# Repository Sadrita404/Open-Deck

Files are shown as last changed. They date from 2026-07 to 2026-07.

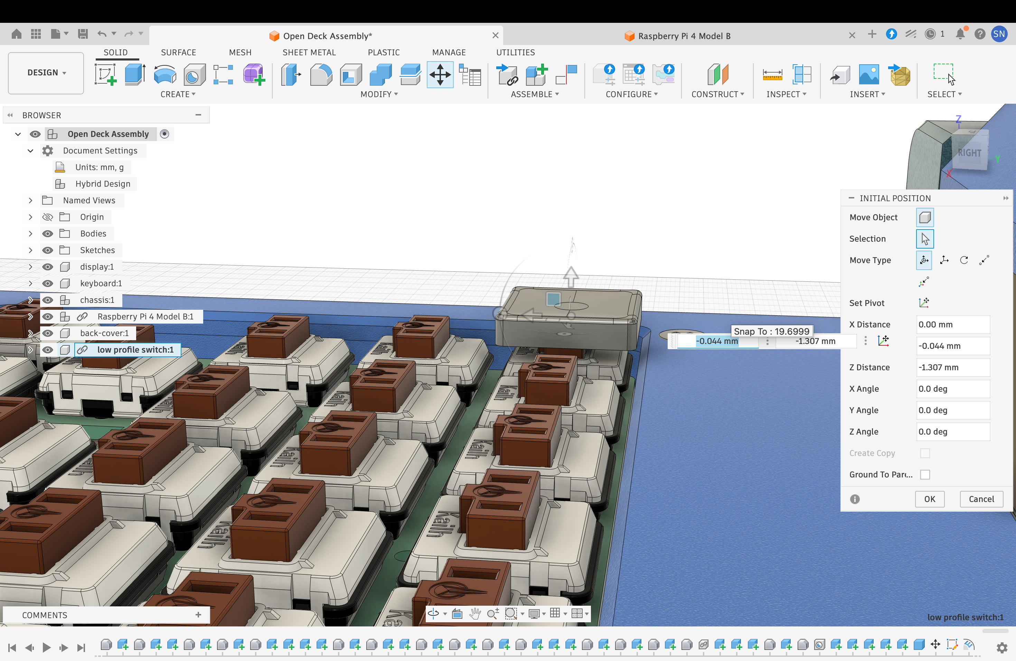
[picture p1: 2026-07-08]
Images/28.png

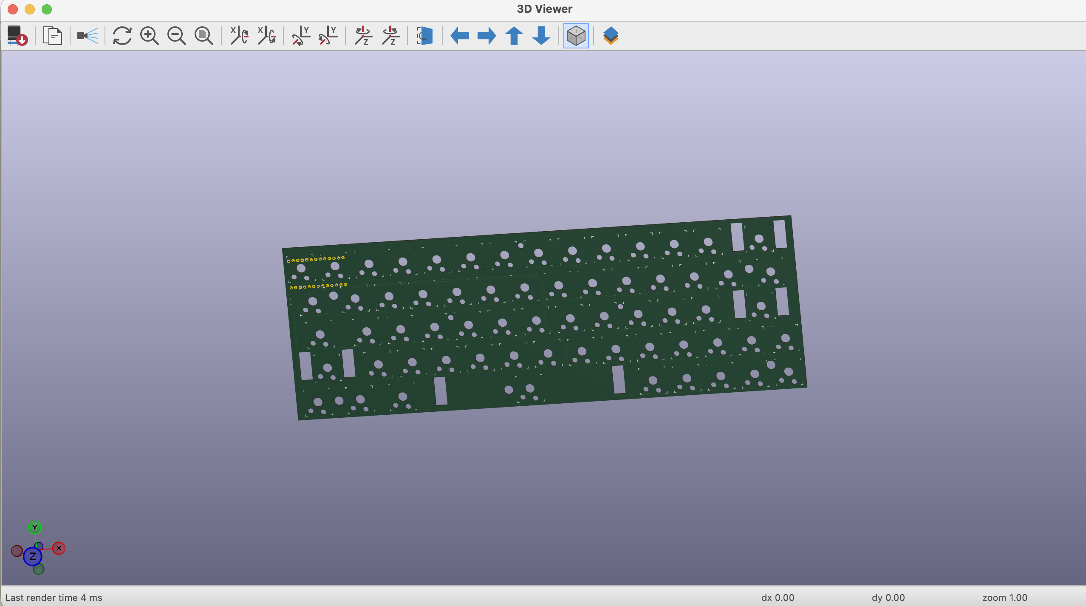
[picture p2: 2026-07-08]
Images/50.png

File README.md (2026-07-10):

<div align="center">
  <table border="0" cellpadding="0" cellspacing="0">
    <tr>
      <td align="center" style="background: #ffffff; border: 1px solid #d0d7de; border-radius: 12px; padding: 16px; box-shadow: 0 4px 12px rgba(0,0,0,0.05);">
        Rough Layout For The PCB
        <div style="margin-top: 12px; font-family: -apple-system, BlinkMacSystemFont, 'Segoe UI', Helvetica, Arial, sans-serif; font-size: 13px; color: #57606a; font-weight: 500;">
      </td>
    </tr>
  </table>
</div>

|Title | Open Deck |
|:-- |:--|
|Author | Sadrita Neogi|

## Overview
It is an fully Open Source Cyber Deck called **Open Deck** Which I have made from scratch it uses an Raspberry Pi 5 Model 2GB RAM as the main compute module and I have made an custom low profile keyboard for this project so that it will perfectly match with the Open Deck . And it also has an pico camera as the webcam .

## Why I chose this project?
Actually I am building an rocket launching system pad and for that I need to track gps , weather , Wind speed , direction a lot on the ground and for that I need something portable that I can use for it and which is seperate from my laptop so that it can run this task independently . Also I am huge fan of this hacking kind of hardware and an cyber deck is something like that so for that reason I have built it ..

##  How to use this project

This project can be used in multiple ways, depending upon the user need  like we can perform basic task like web browsing to fully automate our home to automate our 3-D printers also running some local AI agents into it. There are many possibilities through which we can use this project.For me I will use it to make some projects to be automated and also use in the rocket launching pad for those tasks .

## Features

* It uses custom low profile keyboard 
* It has web cam (pico cam )
* Runs on battery as well an power
* Uses Raspberry Pi 5 Model 2GB RAM
* Compact and Portable 
* Can run local models
* Custom 3d Printed Enclosure
* Fully Open Source 

Schematic

## Software 

For software I will use linux for this build and it is also open source 

**[https://www.raspberrypi.com/software/](https://www.raspberrypi.com/software/)**

### Linux 

**[https://github.com/raspberrypi/linux](https://github.com/raspberrypi/linux)**

### The Linux kernel Documentation - [DOC Link ](https://www.raspberrypi.com/documentation/computers/linux_kernel.html)

In the raspberrypi [website](https://www.raspberrypi.com/documentation/computers/linux_kernel.html) the documentation about downloading and use cases of Linux for raspberrypi is well documented and everything is written there, so please go check it out and read through the documentation. It is well documented and everything is listed there.

---

|  |  | Building Process |  |  |
| :-: | :-: | :-: | :-: | :-: |
| sketch |  |  |  |  |
|  |  |  |  |  |
|  |  |  |  |  |
|  |  |  |  |  |
|  |  |  |  |  |
|  |  |  |  |  |

## Fusion Renders 

<div align="center">

Render 1
Render 3
Render 4
Render 2
Render 6
Render 5

</div>

<div align="center">
  <h2> Bill of Materials</h2>
</div>

| Component Name | Purpose | Qty | Total Price | Source Link | Distributor |
| :--- | :--- | :---: | :---: | :---: | :---: |
| **Raspberry Pi 5 Model B - 2GB RAM** | The Main Board | 1 | $79.20 | [Quartz Components](https://quartzcomponents.com/products/raspberry-pi-5-model-b-2-gb-ram) | Quartzcomponents |
| **HD Portable Monitor IPS Panel Display** | The Main Display | 1 | $58.40 | [Amazon](https://www.amazon.in/Smartchoice-Portable-Adaptive-Sync-Ultra-Slim-Speakers/dp/B082MDD1QZ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) | Amazon |
| **LI-ION BATTERY (3400mAh)** | To power up the circuit | 6 | $23.70 | [Robu](https://robu.in/product/lg-18650-mj1-3400mah-3c-li-ion-battery/) | Robu |
| **Raspberry Pi Camera NOIR V2** | For Webcam | 1 | $16.60 | [Robu](https://robu.in/product/raspberry-pi-camera-noir-v2/) | Robu |
| **Keyboard PCB** | For the main Keyboard | 1 | $17.40 | [JLCPCB](https://jlcpcb.com/) | JLCPCB |
| **Low Profile Brown Switches** | For the Keyboard | 64 | $26.60 | [Stackskb](https://stackskb.com/store/ttc-low-profile-brown-switches-tactile/) | Stackskb |
| **Keycap Set** | For the Keyboard Switch | 1 | $12.00 | [Meckeys](https://meckeys.com/shop/accessories/keyboard-accessories/keycaps/black-cartoon-keycap-set/) | Meckeys |
| **Keyboard Stabilizer** | For the Keyboard | 1 | $10.60 | [Meckeys](https://meckeys.com/shop/accessories/keyboard-accessories/more/glorious-goat-stabilizers/) | Meckeys |
| **Stereo Enclosed Speaker - 3W** | For Sound | 1 | $5.20 | [Robu](https://robu.in/product/dfrobot-fit0502-stereo-enclosed-speaker-3w-8%cf%89/) | Robu |
| **Channel Digital Amplifier Board** | For the Speakers | 1 | $1.50 | [Robu](https://robu.in/product/tpa3110-mono-channel-digital-amplifier-board-30w-power-amplifier-module/) | Robu |
| **Screws Assorted set** | For fixing the frame | 1 | $2.60 | [OnlyScrews](https://onlyscrews.in/products/m3-allen-button-head-ss304-assorted-box) | OnlyScrew |
| **Li - Po BMS module** | For battery protection | 1 | $0.70 | [Robu](https://robu.in/product/3s-12v-18650-lithium-battery-protection-board-12v-10a-overcharge-overcurrent-protection/) | Robu |
| **NRF52840 Development Board** | For the keyboard Controller | 1 | $5.60 | [Electropi](https://www.electropi.in/promicro-nrf52840-development-board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) | Electropi |
| **1N4148 1W Zener Diode** | For the keyboard | 64 | $1.00 | [Robu](https://robu.in/product/1n4148-1w-zener-diode-pack-of-50/) | Robu |
| **20 pin header socket** | For the keyboard | 1 | $0.20 | [Robu](https://robu.in/product/2-54mm-1x20-pin-female-single-row-straight-header-strip-pack-of-5/) | Robu |
| **Self Locking Switch** | For the power switch | 1 | $0.40 | [Robu](https://robu.in/product/r16-503a-plastic-self-locking-latching-switch-2pinoff-on/) | Robu |
| **USB-C hub module** | For the Cyber Deck Ports | 1 | $2.60 | [Robu](https://robu.in/product/smartelex-usb-hub-with-4x-usb-2-0-ports/) | Robu |
| **Raspberry Pi 5 Active Cooler** | To cool the Pi | 1 | $5.10 | [Robu](https://robu.in/product/official-raspberry-pi-5-active-cooler/) | Robu |
| **Flat Ribbon HDMI + Short Type-C Extensions** | For Display Connection | 1 | $1.50 | [Robu](https://robu.in/product/micro-hdmi-male-to-hdmi-male-adapter/) | Robu |
| **3d Print** | For the Case and the body | 1 | $0.00 | [Print Legion](https://printlegion.hackclub.com/) | #printing-legion |
| **Tax** | - | - | $3.60 | - | - |
| **Shipping** | incl. PCB | - | $22.00 | - | - |
| **Total** | - | - | $290.00 | - | - |
| **Total Round Off** | For Dollar rate fluctuation | - | $300.00 | - | - |

## Copyright and License
Copyright (c) 2026 Sadrita Neogi. All rights reserved.

All files are licensed under the MIT license. For more information, see the [LICENSE](LICENSE).

Project Under Hack Club

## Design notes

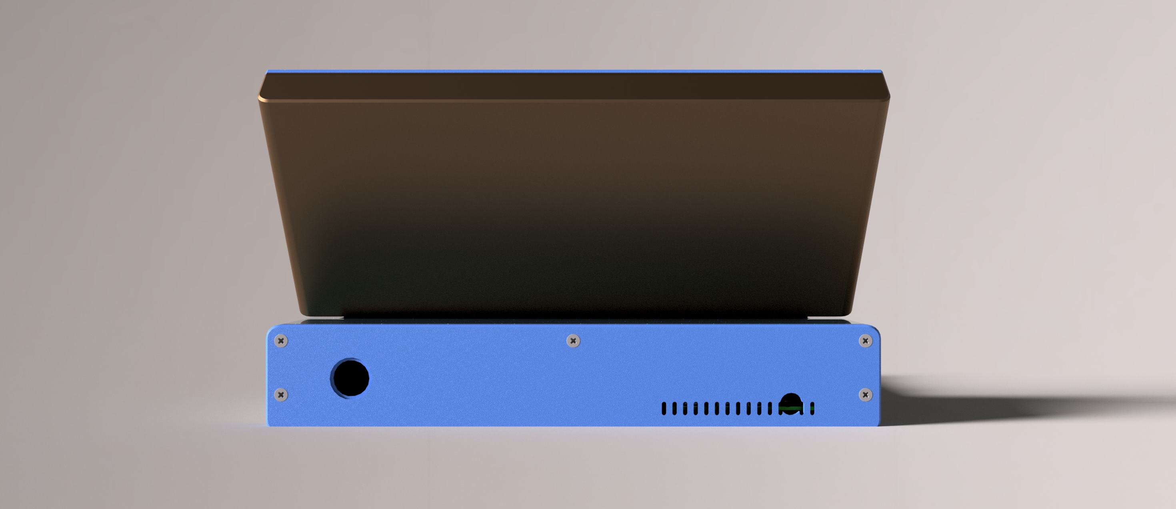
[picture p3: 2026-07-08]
Renders/Render 2.png

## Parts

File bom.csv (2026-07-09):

Name | Purpose | Quantity | Total Cost (USD) | Link | Distributor
Raspberry Pi 5 Model B - 2GB RAM | The Main Board | 1 | 79.2 | https://quartzcomponents.com/products/raspberry-pi-5-model-b-2-gb-ram?variant=44765133734122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 | Quartzcomponents
HD Portable Monitor IPS Panel Display | The Main Display | 1 | 58.4 | https://www.amazon.in/Smartchoice-Portable-Adaptive-Sync-Ultra-Slim-Speakers/dp/B082MDD1QZ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 | Amazon
LI-ION BATTERY (3400mAh) | To power up the circuit | 6 | 23.7 | https://robu.in/product/lg-18650-mj1-3400mah-3c-li-ion-battery/ | Robu
Raspberry Pi Camera NOIR V2 | For Webcam | 1 | 16.6 | https://robu.in/product/raspberry-pi-camera-noir-v2/ | Robu
Keyboard PCB | For the main Keyboard | 1 | 17.40 | https://jlcpcb.com/ | JLCPCB
Low Profile Brown Switches | For the Keyboard | 64 | 26.6 | https://stackskb.com/store/ttc-low-profile-brown-switches-tactile/ | Stackskb
Keycap Set | For the Keyboard Switch | 1 | 12 | https://meckeys.com/shop/accessories/keyboard-accessories/keycaps/black-cartoon-keycap-set/ | Meckeys
Keyboard Stabilizer | For the Keyboard | 1 | 10.6 | https://meckeys.com/shop/accessories/keyboard-accessories/more/glorious-goat-stabilizers/ | Meckeys
Stereo Enclosed Speaker - 3W | For Sound | 1 | 5.2 | https://robu.in/product/dfrobot-fit0502-stereo-enclosed-speaker-3w-8%cf%89/ | Robu
Channel Digital Amplifier Board | For the Speakers | 1 | 1.5 | https://robu.in/product/tpa3110-mono-channel-digital-amplifier-board-30w-power-amplifier-module/ | Robu
Screws Assorted set | For fixing the frame | 1 | 2.6 | https://onlyscrews.in/products/m3-allen-button-head-ss304-assorted-box | OnlyScrew
Li - Po BMS module | For battery protection | 1 | 0.7 | https://robu.in/product/3s-12v-18650-lithium-battery-protection-board-12v-10a-overcharge-overcurrent-protection/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 | Robu
NRF52840 Development Board | For the keyboard Controller | 1 | 5.6 | https://www.electropi.in/promicro-nrf52840-development-board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 | Electropi
1N4148 1W Zener Diode | For the keyboard | 64 | 1 | https://robu.in/product/1n4148-1w-zener-diode-pack-of-50/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 | Robu
20 pin header socket | For the Keyboard | 1 | 0.2 | https://robu.in/product/2-54mm-1x20-pin-female-single-row-straight-header-strip-pack-of-5/?gad_source=1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 | Robu
Self Locking Switch | For the power switch | 1 | 0.4 | https://robu.in/product/r16-503a-plastic-self-locking-latching-switch-2pinoff-on/?gad_source=1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 | Robu
USB-C hub module | For the Cyber Deck Ports | 1 | 2.6 | https://robu.in/product/smartelex-usb-hub-with-4x-usb-2-0-ports/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 | Robu
Raspberry Pi 5 Active Cooler | To cool the Pi | 1 | 5.1 | https://robu.in/product/official-raspberry-pi-5-active-cooler/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 | Robu
Flat Ribbon HDMI + Short Type-C Extensions | For Display Connection | 1 | 1.5 | https://robu.in/product/micro-hdmi-male-to-hdmi-male-adapter/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 | Robu
3d Print | For the Case and the body | 1 | 0 | https://printlegion.hackclub.com/ | #printing-legion
Tax |  |  | 3.6
Shipping | incl. PCB |  | 22
Total |  |  | 290
Total Round Off | For Dollar rate fluctuation |  | 300

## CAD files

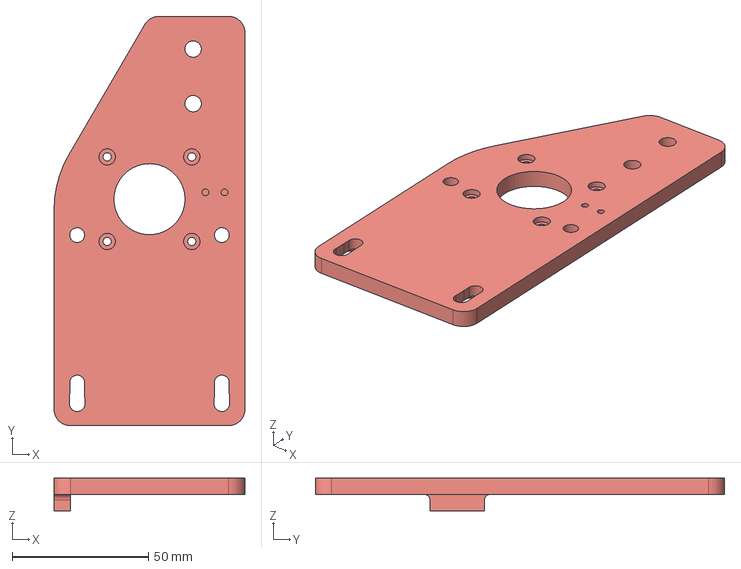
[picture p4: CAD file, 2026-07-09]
CAD/Front case.step
70.0 x 150.0 x 12.0 mm

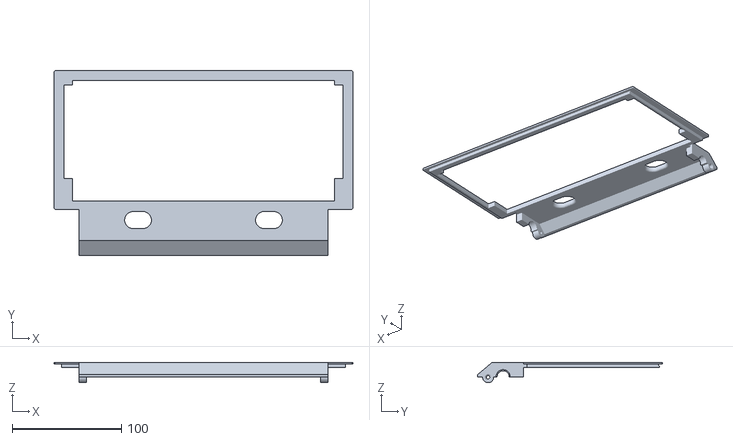
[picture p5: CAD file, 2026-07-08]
Printed Parts/Display-bezel.stl
274.0 x 169.1 x 18.7

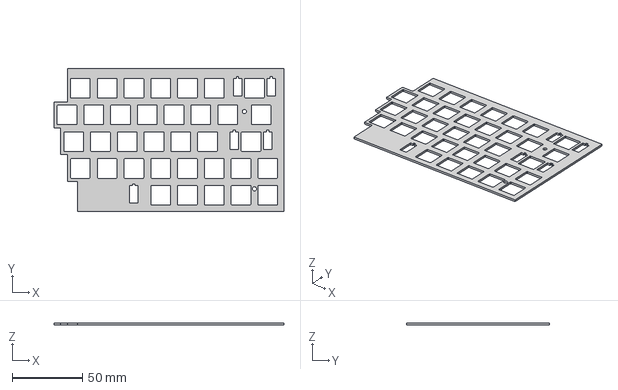
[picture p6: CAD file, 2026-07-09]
CAD/enclosure-plate_right.step
163.6 x 101.6 x 1.50 mm

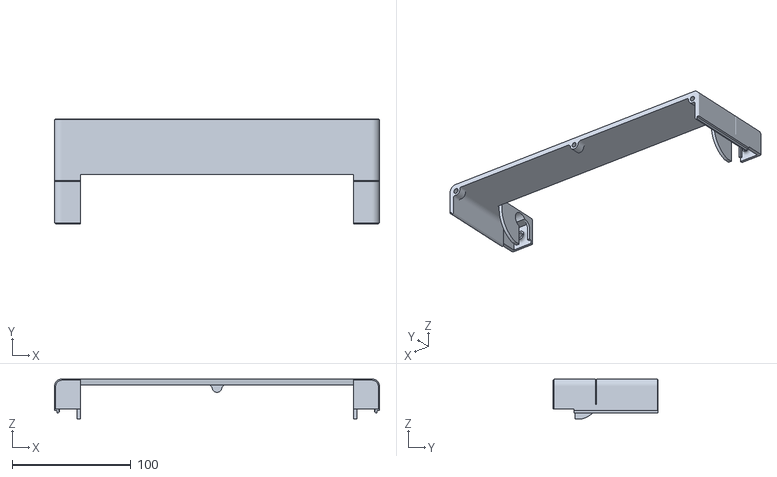
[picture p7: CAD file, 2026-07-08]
Printed Parts/Top-cover.stl
274.0 x 88.6 x 33.6

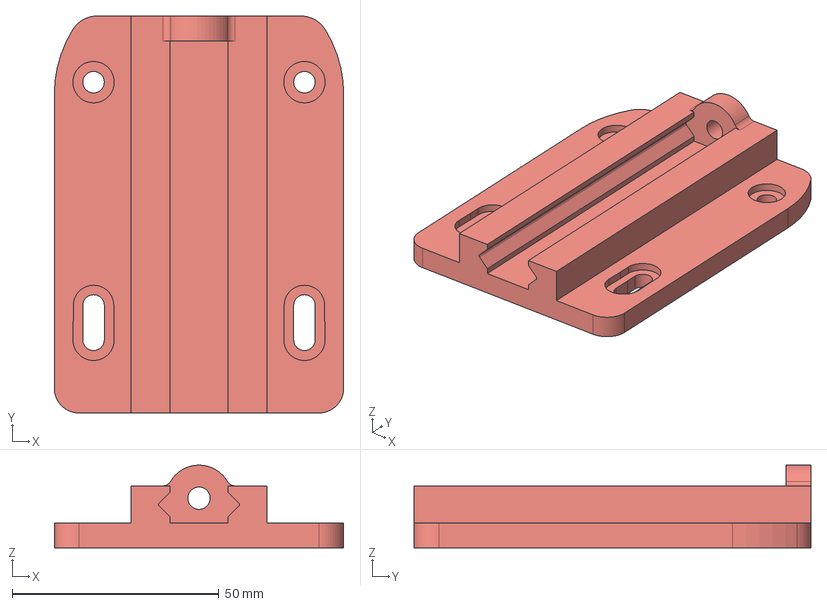
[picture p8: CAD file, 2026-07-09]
CAD/base plate.step
70.0 x 96.0 x 20.0 mm

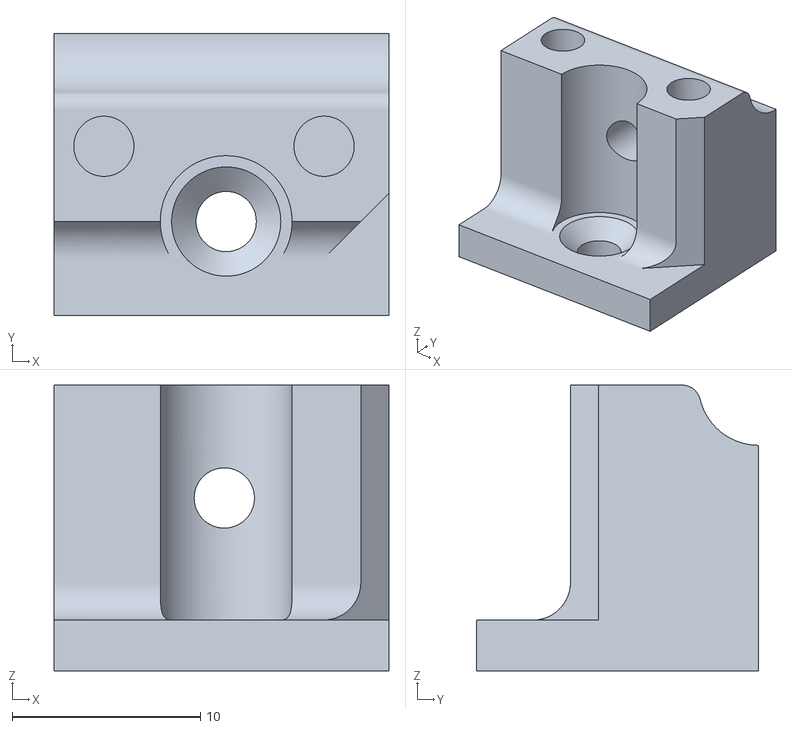
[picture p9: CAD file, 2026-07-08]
Printed Parts/Pivot-point-right.stl
17.8 x 15.0 x 15.2

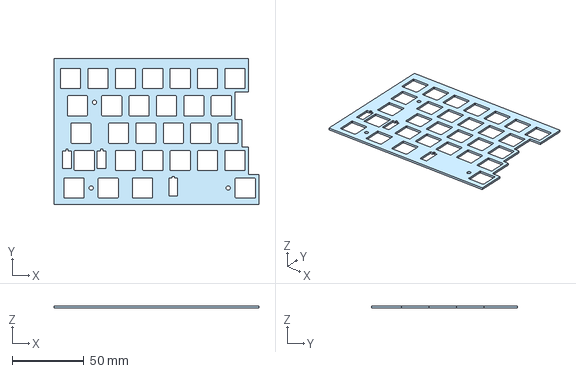
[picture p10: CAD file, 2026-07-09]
CAD/enclosure-plate_left.step
142.5 x 101.6 x 1.50 mm

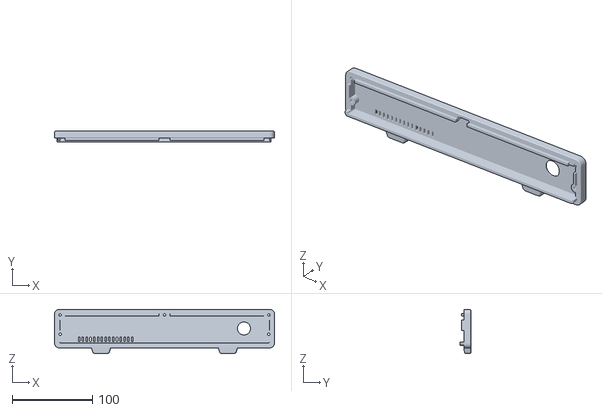
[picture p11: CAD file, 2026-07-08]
Printed Parts/Back-cover.stl
274.0 x 13.6 x 55.1

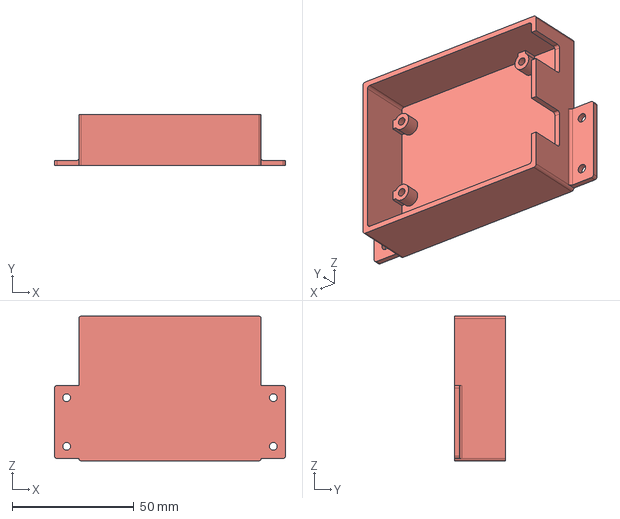
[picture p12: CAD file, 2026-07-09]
CAD/Controller holder.step
95.0 x 21.0 x 59.6 mm

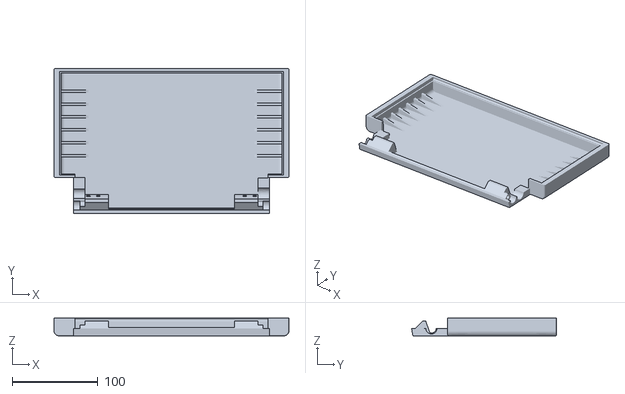
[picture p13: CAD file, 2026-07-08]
Printed Parts/Display.stl
274.0 x 169.1 x 20.8

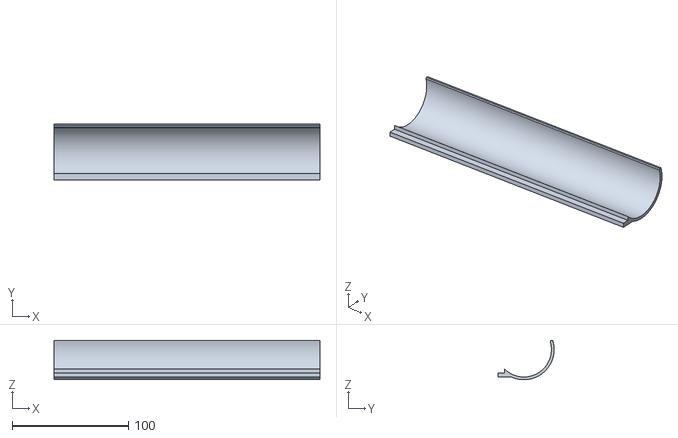
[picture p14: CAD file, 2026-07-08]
Printed Parts/Hinge-Cover.stl
229.0 x 48.4 x 33.9

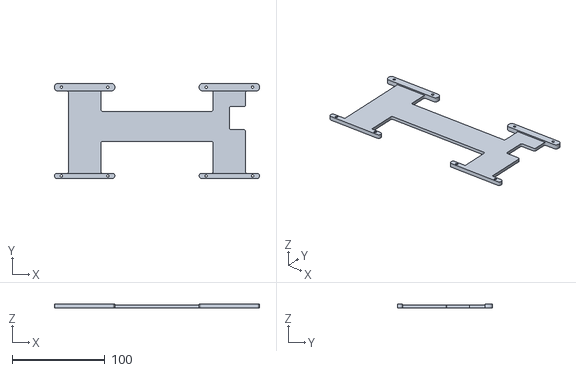
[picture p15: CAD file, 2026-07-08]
Printed Parts/Keyboard-bracket.stl
221.0 x 102.5 x 4.80

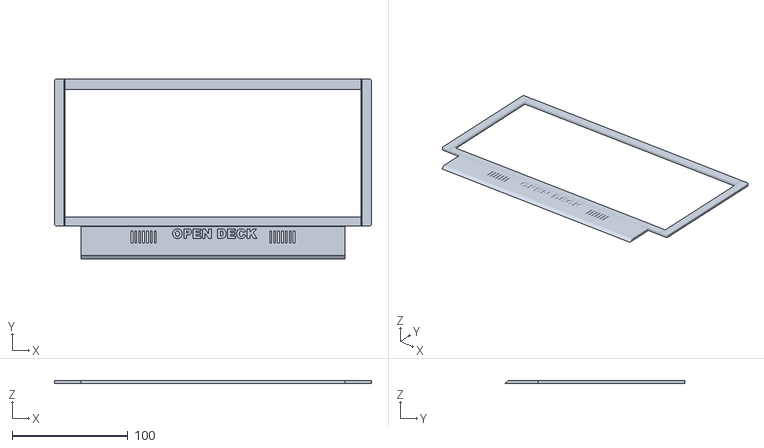
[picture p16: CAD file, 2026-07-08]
Printed Parts/Display Front.stl
274.0 x 155.8 x 2.50

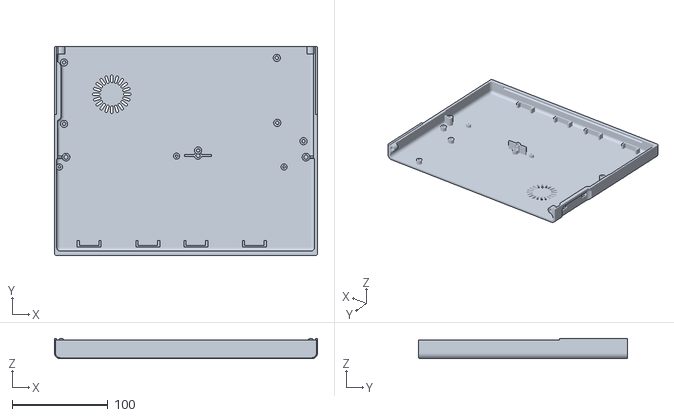
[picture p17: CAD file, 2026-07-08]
Printed Parts/Chassis.stl
274.0 x 217.5 x 21.3

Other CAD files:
Printed Parts/Pivot-point-left.stl
Printed Parts/keyboard-plate.stl

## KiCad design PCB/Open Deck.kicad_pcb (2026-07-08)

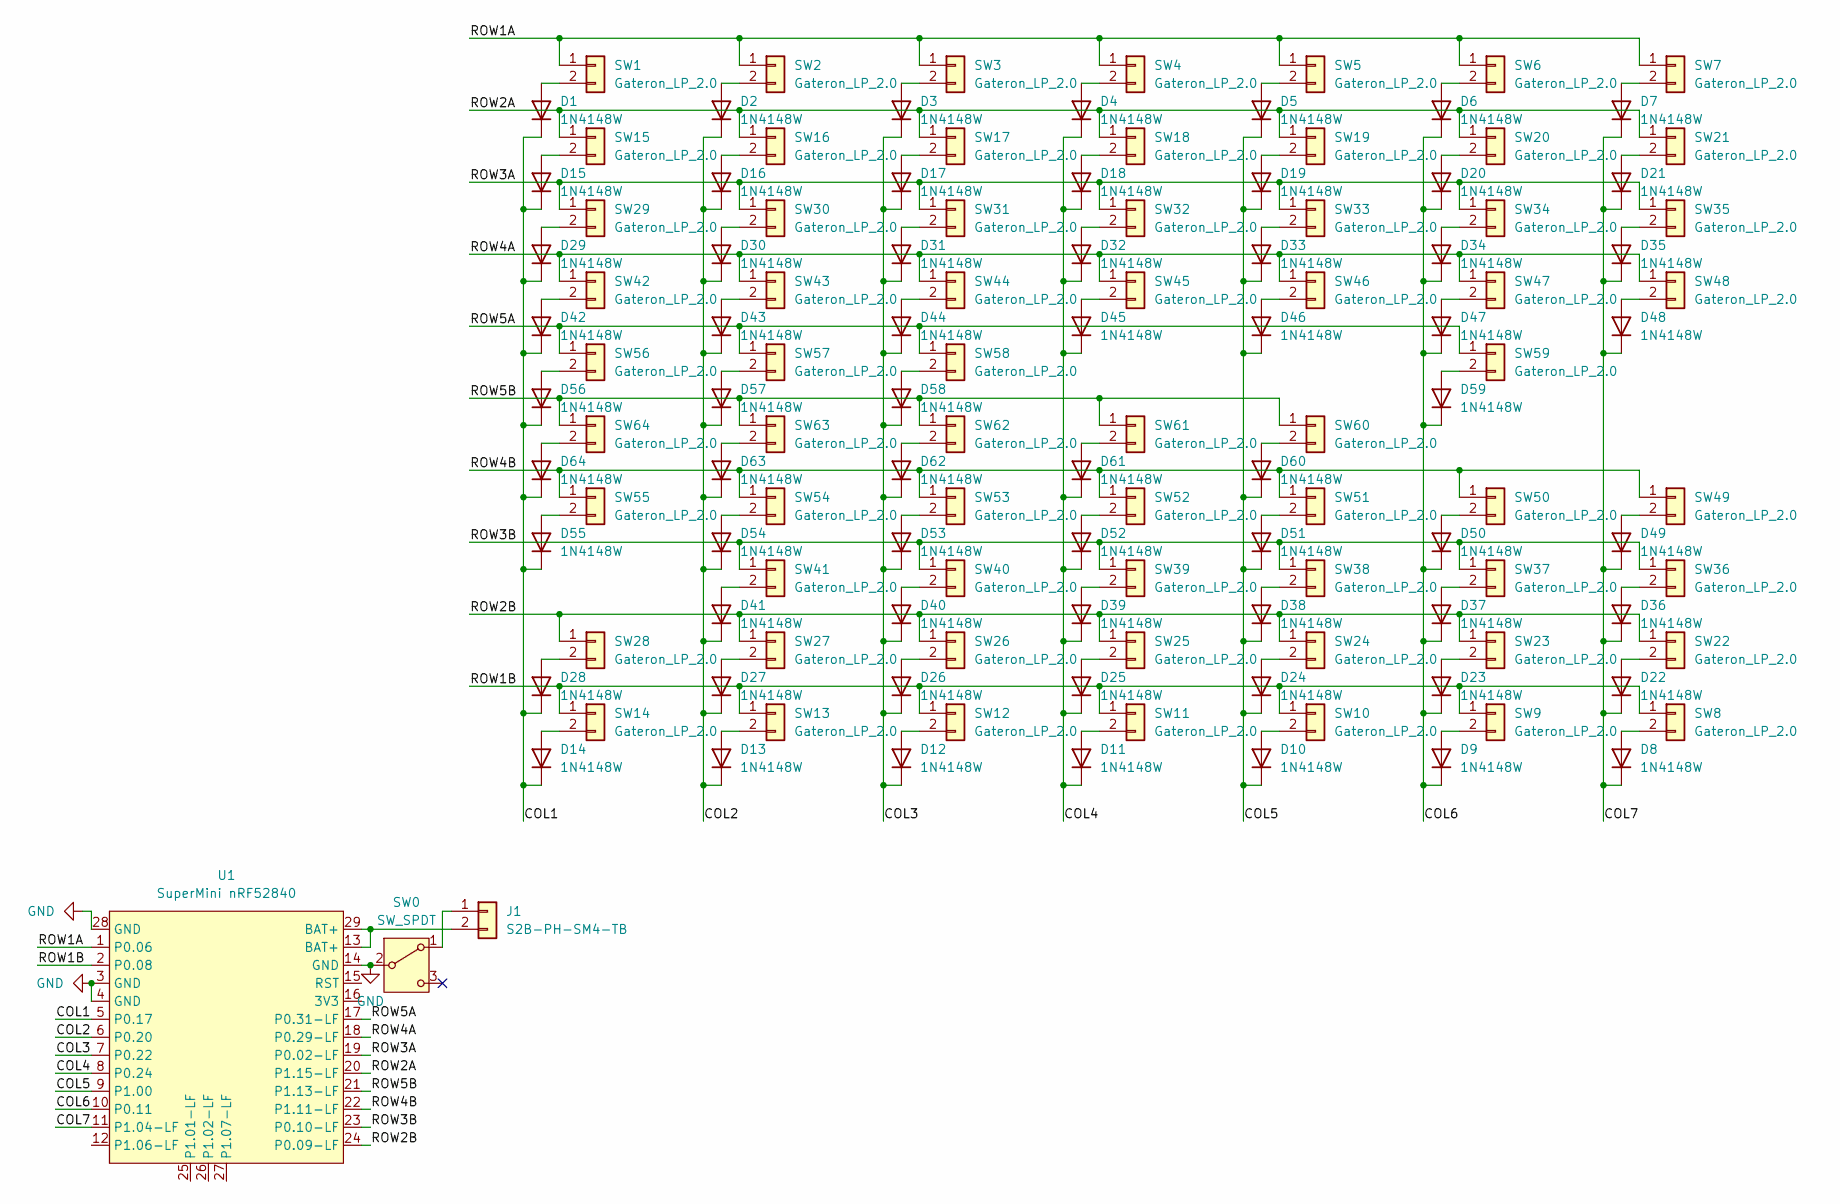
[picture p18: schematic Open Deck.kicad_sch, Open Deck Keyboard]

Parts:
D1, D2, D3, D4, D5, D6, D7, D8, D9, D10, D11, D12, D13, D14, D15, D16, D17, D18, D19, D20, D21, D22, D23, D24, D25, D26, D27, D28, D29, D30, D31, D32, D33, D34, D35, D36, D37, D38, D39, D40, D41, D42, D43, D44, D45, D46, D47, D48, D49, D50, D51, D52, D53, D54, D55, D56, D57, D58, D59, D60, D61, D62, D63, D64: 1N4148W; D_SOD-123
J1: S2B-PH-SM4-TB; JST_PH_S2B-PH-SM4-TB_1x02-1MP_P2.00mm_Horizontal
SW0: SW_SPDT; SW_SSSS811101
SW1, SW2, SW3, SW4, SW5, SW6, SW7, SW8, SW9, SW10, SW11, SW12, SW13, SW14, SW15, SW16, SW17, SW18, SW19, SW20, SW21, SW22, SW23, SW24, SW25, SW26, SW27, SW28, SW29, SW30, SW31, SW32, SW33, SW34, SW35, SW36, SW37, SW38, SW39, SW40, SW41, SW42, SW43, SW44, SW45, SW46, SW47, SW48, SW49, SW50, SW51, SW52, SW53, SW54, SW55, SW56, SW57, SW58, SW59, SW60, SW61, SW62, SW63, SW64: Gateron_LP_2.0
U1: SuperMini nRF52840; SuperMini_nRF52840_AH_USBup

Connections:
/COL1: D1.1 (K), D14.1 (K), D15.1 (K), D28.1 (K), D29.1 (K), D42.1 (K), D55.1 (K), D56.1 (K), D64.1 (K), U1.5 (P0.17)
/COL2: D2.1 (K), D13.1 (K), D16.1 (K), D27.1 (K), D30.1 (K), D41.1 (K), D43.1 (K), D54.1 (K), D57.1 (K), D63.1 (K), U1.6 (P0.20)
/COL3: D3.1 (K), D12.1 (K), D17.1 (K), D26.1 (K), D31.1 (K), D40.1 (K), D44.1 (K), D53.1 (K), D58.1 (K), D62.1 (K), U1.7 (P0.22)
/COL4: D4.1 (K), D11.1 (K), D18.1 (K), D25.1 (K), D32.1 (K), D39.1 (K), D45.1 (K), D52.1 (K), D61.1 (K), U1.8 (P0.24)
/COL5: D5.1 (K), D10.1 (K), D19.1 (K), D24.1 (K), D33.1 (K), D38.1 (K), D46.1 (K), D51.1 (K), D60.1 (K), U1.9 (P1.00)
/COL6: D6.1 (K), D9.1 (K), D20.1 (K), D23.1 (K), D34.1 (K), D37.1 (K), D47.1 (K), D50.1 (K), D59.1 (K), U1.10 (P0.11)
/COL7: D7.1 (K), D8.1 (K), D21.1 (K), D22.1 (K), D35.1 (K), D36.1 (K), D48.1 (K), D49.1 (K), U1.11 (P1.04-LF)
/ROW1A: SW1.1, SW2.1, SW3.1, SW4.1, SW5.1, SW6.1, SW7.1, U1.1 (P0.06)
/ROW1B: SW8.1, SW9.1, SW10.1, SW11.1, SW12.1, SW13.1, SW14.1, U1.2 (P0.08)
/ROW2A: SW15.1, SW16.1, SW17.1, SW18.1, SW19.1, SW20.1, SW21.1, U1.20 (P1.15-LF)
/ROW2B: SW22.1, SW23.1, SW24.1, SW25.1, SW26.1, SW27.1, SW28.1, U1.24 (P0.09-LF)
/ROW3A: SW29.1, SW30.1, SW31.1, SW32.1, SW33.1, SW34.1, SW35.1, U1.19 (P0.02-LF)
/ROW3B: SW36.1, SW37.1, SW38.1, SW39.1, SW40.1, SW41.1, U1.23 (P0.10-LF)
/ROW4A: SW42.1, SW43.1, SW44.1, SW45.1, SW46.1, SW47.1, SW48.1, U1.18 (P0.29-LF)
/ROW4B: SW49.1, SW50.1, SW51.1, SW52.1, SW53.1, SW54.1, SW55.1, U1.22 (P1.11-LF)
/ROW5A: SW56.1, SW57.1, SW58.1, SW59.1, U1.17 (P0.31-LF)
/ROW5B: SW60.1, SW61.1, SW62.1, SW63.1, SW64.1, U1.21 (P1.13-LF)
GND: SW0.2 (B), U1.3 (GND), U1.4 (GND), U1.14 (GND), U1.28 (GND)
unnamed: D1.2 (A), SW1.2
unnamed: D2.2 (A), SW2.2
unnamed: D3.2 (A), SW3.2
unnamed: D4.2 (A), SW4.2
unnamed: D5.2 (A), SW5.2
unnamed: D6.2 (A), SW6.2
unnamed: D7.2 (A), SW7.2
unnamed: D8.2 (A), SW8.2
unnamed: D9.2 (A), SW9.2
unnamed: D10.2 (A), SW10.2
unnamed: D11.2 (A), SW11.2
unnamed: D12.2 (A), SW12.2
unnamed: D13.2 (A), SW13.2
unnamed: D14.2 (A), SW14.2
unnamed: D15.2 (A), SW15.2
unnamed: D16.2 (A), SW16.2
unnamed: D17.2 (A), SW17.2
unnamed: D18.2 (A), SW18.2
unnamed: D19.2 (A), SW19.2
unnamed: D20.2 (A), SW20.2
unnamed: D21.2 (A), SW21.2
unnamed: D22.2 (A), SW22.2
unnamed: D23.2 (A), SW23.2
unnamed: D24.2 (A), SW24.2
unnamed: D25.2 (A), SW25.2
unnamed: D26.2 (A), SW26.2
unnamed: D27.2 (A), SW27.2
unnamed: D28.2 (A), SW28.2
unnamed: D29.2 (A), SW29.2
unnamed: D30.2 (A), SW30.2
unnamed: D31.2 (A), SW31.2
unnamed: D32.2 (A), SW32.2
unnamed: D33.2 (A), SW33.2
unnamed: D34.2 (A), SW34.2
unnamed: D35.2 (A), SW35.2
unnamed: D36.2 (A), SW36.2
unnamed: D37.2 (A), SW37.2
unnamed: D38.2 (A), SW38.2
unnamed: D39.2 (A), SW39.2
unnamed: D40.2 (A), SW40.2
unnamed: D41.2 (A), SW41.2
unnamed: D42.2 (A), SW42.2
unnamed: D43.2 (A), SW43.2
unnamed: D44.2 (A), SW44.2
unnamed: D45.2 (A), SW45.2
unnamed: D46.2 (A), SW46.2
unnamed: D47.2 (A), SW47.2
unnamed: D48.2 (A), SW48.2
unnamed: D49.2 (A), SW49.2
unnamed: D50.2 (A), SW50.2
unnamed: D51.2 (A), SW51.2
unnamed: D52.2 (A), SW52.2
unnamed: D53.2 (A), SW53.2
unnamed: D54.2 (A), SW54.2
unnamed: D55.2 (A), SW55.2
unnamed: D56.2 (A), SW56.2
unnamed: D57.2 (A), SW57.2
unnamed: D58.2 (A), SW58.2
unnamed: D59.2 (A), SW59.2
unnamed: D60.2 (A), SW60.2
unnamed: D61.2 (A), SW61.2
unnamed: D62.2 (A), SW62.2
unnamed: D63.2 (A), SW63.2
unnamed: D64.2 (A), SW64.2
unnamed: J1.1, SW0.1 (A)
unnamed: J1.2, U1.13 (BAT+), U1.29 (BAT+)

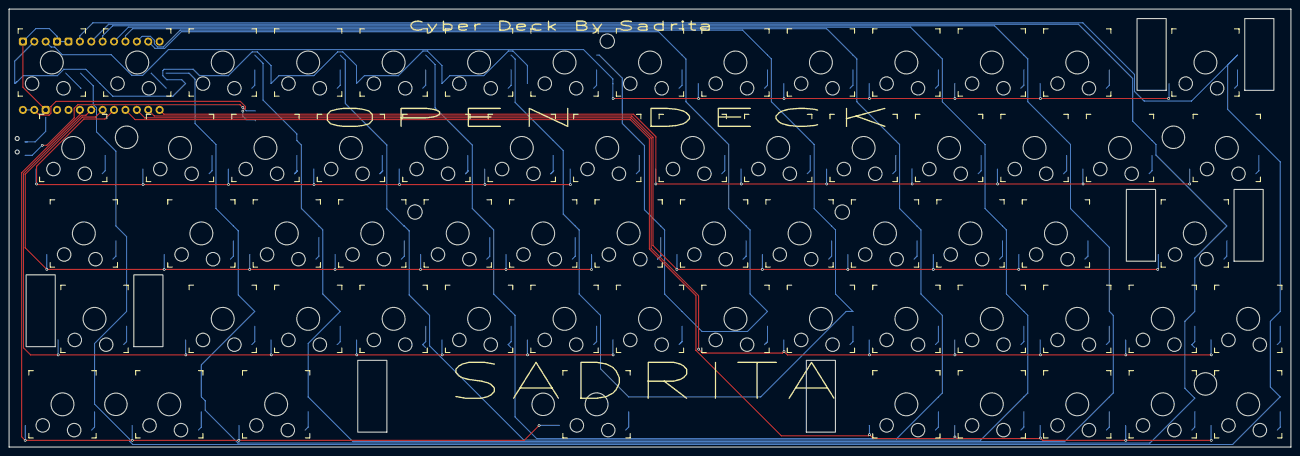
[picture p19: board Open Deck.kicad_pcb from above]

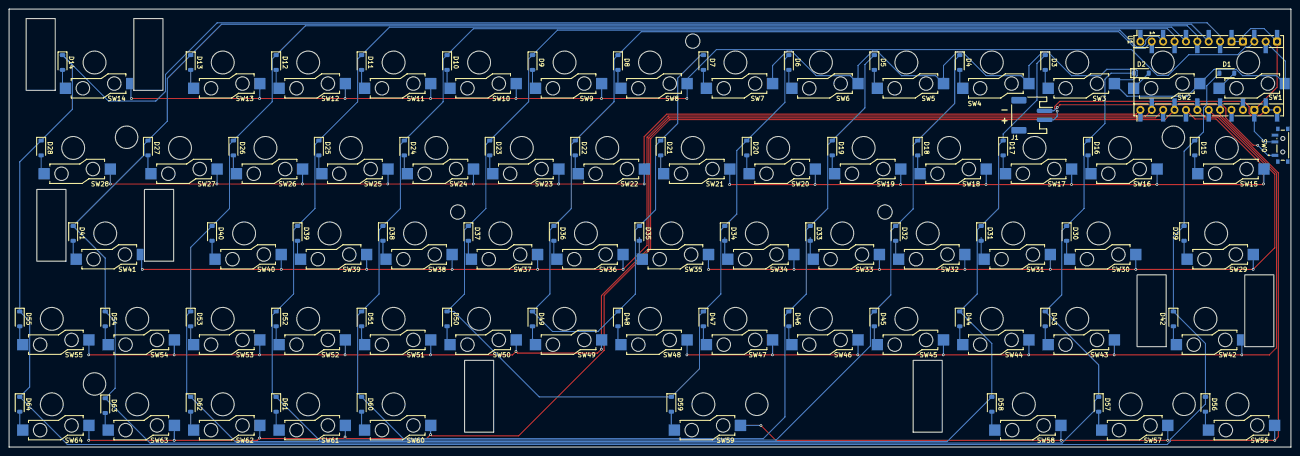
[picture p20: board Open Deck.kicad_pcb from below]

Board: 2 copper layers, 285.8 x 97.6 mm, 131 parts (67 on the bottom side), 84 nets.

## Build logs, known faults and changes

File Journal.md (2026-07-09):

| Title | Open Deck|
| :-- | :---|
|Author |Sadrita Neogi|
|Type | Cyber Deck  |
Total Hrs | 19.5 |

# Making the Rough Sketch of the Open Deck and Reserch 

So today I went online and take inspo of other cyber deck and after that I went to start designing my own , it's an rough sketch of the build and it will help me in the CAD to build the real one in Fusion 360.

Screenshot 2026-07-09 at 9 48 04 AM

Screenshot 2026-07-09 at 9 48 38 AM

Screenshot 2026-07-09 at 9 49 00 AM







**Inspo**

Screenshot 2026-07-09 at 9 46 54 AM
Screenshot 2026-07-09 at 9 46 35 AM

**Mine**

sketch

_Total Time Spent = 2.2hr_

---

# Started With the CAD 

**But First I need to take all the dimension for each of the components**





Before starting with the CAD design, first, I need to take the dimension for each of the components so that I can make the case and inclusion for the open deck to be exactly perfect and nothing can be go wrong, so I take that data sheet of each of the components, then I write it down on a paper, and now I am starting with the CAD design















_Total Time Spent = 4hr_

---
## Working on the PCB 

In the first thought, I was thinking to get an normal keyboard which is readily available online, but then I thought that they won't make the cyber deck to be special so I thought that why not I designed my own keyboard for this bill, so now I have started designing my own keyboard PCB for this cyber  deck









_Total Time Spent = 2.2hr_

---

# PCB layout and routing all the traces

So I have completed the schematic for this keyboard. I have used my old projects inspiration from the split keyboard that I have made and I have converted into the full size keyboard. Then I completed the schematic of the bill and now it's time to get the layout of the PCB and make it done..



Screenshot 2026-07-09 at 10 28 00 AM





_Total Time Spent = 3.3hr_

---

# Adding the silk screen to the PCB 

So after completing with design designing the PCB now, why make the PCB want to make a little bit Looks good. I know that the PCB will not be visible in the world, but still I want to add a good silk screen to this PCB 

Screenshot 2026-07-09 at 10 29 32 AM





_Total Time Spent = 0.4hr_

---

# completed the keyboard and the controller board

So now today I added the computer boot and rest of the keyboard parts in the CAD file and make it complete by this part also this took me alot of time in take the Raspberry Pi Pico cad model online for the keyboard but then I found it on the Grab Cad and it was perfect for it let's see how it looks in the final build ..















_Total Time Spent = 2.4hr_

---

# Correcting the hinge for

So researching, I found out that since I will going to 3-D print all the parts, the case and the hinges I have come up with an good idea like I will add groups to the hinge so that it can be easily open and close, and it will stay at it place on a long run and it will not tear up while using so I have designed it, and I made it simple so that it can be easily modify later if needed








_Total Time Spent = 0.4hr_

---

# Working in the back air vents and the port's

Software designing, most of the CAD part in fusion 360 I found out that I also need to make air vents for the micro controller so that it can be cool throughout the time. It is turning on so that I can get better thermal performance. So for that reason I have cut out vents for that..









_Total Time Spent = 0.8hr_

---

# Adding the Main Screen 

So after taking the dimensions from the screen that I wanted to add in this bill, I started designing and blank box in fusion 360. Actually, I couldn't find the exact model online and I just made one for myself with the accurate dimension. It is not exactly the look how it would be turned out, but I just need the right dimension for that so that I can put it into the final assembly file.







I have also embedded the name of this build in the fron case and it look cool 





_Total Time Spent = 0.6hr_

---

# Adding the Key Caps to the Switches 

So after completing with all the basic CAD work now I have finalised the key caps that I wanted to put since I wanted to be Lofi since I need to also close the lead of the screen, so I am going with an low profile key caps with this bill and I have put all of the key caps in and I couldn't find the CAD model for the space bar and the tab, so I have made one I will say. I have improvise it like kind of making similar to how it would be look in the actual.













**Making the Space Bar**













_Total Time Spent = 1.5hr_

---

# adding appearance to the key caps 

So after completing with adding all the keycaps to all the switches now I need to render images of the final assembly bill, so I need to put some colour in the key cap that I want to get so for that, I have added appearance to all the key caps







_Total Time Spent = 0.4hr_

---

# now image rendering in Fusion 360 

So, I have finally completed with all the assembly CAD model now to make the Git hub repo I need some good images of the project build. So now I want to render some images. I have not much experience in rendering images, basically fusion 360. In my earlier project, I used to disable the visibility grid line in the working area. Then I used to take screenshot of it. But later I found out that I have dedicated option in fusion 360 where I can render images. I also download an HDR 360 environment for it, and I have used it to render the images.





## Final Renders Looks good to me..

Render 1

Render 2

Render 3

Render 4

Render 5

Render 6

It took me a lot of time like in setting up the environment and checking all the lighting conditions to get some good renders

_Total Time Spent = 1.3hr_

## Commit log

2026-07-08 all added
    [Back-cover.stl, Chassis.stl, Display Front.stl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]
2026-07-08 PCB and Images
    [Open Deck-B_Cu.gbr, Open Deck-B_Mask.gbr, Open Deck-B_Paste.gbr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]
2026-07-09 printed parts added
2026-07-09 cad file
    [Controller holder.step, Front case.step, base plate.step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]
